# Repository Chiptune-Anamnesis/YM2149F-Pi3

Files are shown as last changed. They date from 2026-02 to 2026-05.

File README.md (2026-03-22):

# YM2149Fx3 MIDI Synthesizer

Triple YM2149F sound chip MIDI synthesizer with SID emulation, sample playback, and real-time sound design — powered by RP2040 (Raspberry Pi Pico).

## Features

### 9-Voice Polyphonic YM2149F Synthesis
- 3x YM2149F sound chips providing 9 independent tone voices
- **Four voice allocation modes:**
  - **MONO** — 1 voice per MIDI channel (ch1→voice 0A, ch2→0B, ... ch9→2C). Each channel has independent settings. True 9-channel multitimbral.
  - **SEMI** — 3 voices per chip, MIDI channel determines chip (ch1-3→Chip 0, ch4-6→Chip 1, ch7-9→Chip 2). Channel-based settings.
  - **POLY** — Up to 9-voice polyphony, any voice on any chip. Notes allocated to first free voice. Per-voice settings for individual voice tweaking and chip linking.
  - **MULTI** — Full polyphony like POLY, but settings follow MIDI channel instead of physical voice. Best for multi-channel DAW sequencing where each channel needs its own vibrato, envelope, detune, etc.
- Per-voice settings: detune (cents), octave shift, max volume, noise frequency
- Chip linking: mirror Chip 0 settings across chips for massive unison sounds
- MIDI channels 1-9 mapped to voices (3 per chip)

### SID Emulation Mode (NextSID)
- Software-emulated SID-style waveforms on Chips 1 and 2 (6 voices)
- Waveforms: Square and Pulse with adjustable duty cycle (default duty: 11)
- PWM sweep with configurable rate and depth
- Per-voice sync and ring modulation between voices within a chip
- Noise mixing per voice
- Portamento/glide fully supported in SID mode
- ~50kHz timer-driven volume flipping for waveform generation

### Sample Playback (SMPL Mode)
- Timer-based 8-bit PCM playback at 8000 Hz on Chip 2 (3 polyphonic voices)
- **Three sample sections:**
  - **DRUM** — 24 Bitkits drum samples: kicks, snares, hi-hats, toms, claps, cowbell, tambourine, shaker
  - **1SHT** — 24 Bitkits one-shot samples: beeps, blips, buzzes, glitches, metals, noises, stabs, vocals, zaps
  - **DIGI** — 16 legacy ST-Sound DigiDrum samples (classic Atari ST sounds)
- **Four playback modes:**
  - **SNGL** — Always play the selected sample
  - **SEQ** — Play samples sequentially (s00, s01, s02...)
  - **RND** — Random sample each trigger
  - **GM** — General MIDI drum map (notes 35-58 mapped to samples). OneShots use chromatic mapping from C2
- Per-section GM drum maps (Bitkits and DigiDrum have independent mappings)
- Pitch control: -12 to +12 semitones fine tuning plus -3 to +3 octave shift (8.8 fixed-point)
- Adjustable sample length (1-127, 127 = full sample)
- Volume scaling (1-15)
- Voice stealing with same-sample retrigger and round-robin allocation

### Effects (Chip 2)
- **Echo** — Delay, repeats, decay, volume
- **Arpeggio** — Speed, pattern, volume, octave range
- **Bit Crush** — Bit depth, sample rate, volume
- **Reverb** — Taps, spacing, decay, detune, volume
- **Chorus** — Detune spread with configurable volume
- Flexible routing: per-chip or global

### Per-Voice Modulation
- **Vibrato** — Rate (1.0-15.0 Hz), depth (0-200 cents), delay (0-2550ms)
- **Tremolo** — Rate (1.0-15.0 Hz), depth (0-100%)
- **Pitch Envelope** — Amount (0-24 semitones), time, direction (up/down)
- **ADSR Envelope** — Attack, decay, sustain, release
- **Portamento/Glide** — On/off per voice, adjustable speed

### Preset System
- Save and load complete synth states to flash (8 user slots)
- 4 factory SID presets
- Stores all voice settings, FX, SID config, sample section, mode, and more
- 8-character preset naming

### MIDI Implementation
- USB-MIDI and TRS-MIDI (Serial1 at 31250 baud) simultaneously
- MIDI channel filtering (per-channel, OMNI, or OFF)
- Channel remapping (route any incoming channel to any internal channel)
- 74 MIDI CC mappings covering voice, envelope, tremolo, FX, sample, and link controls — see [MIDI CC Map](MIDI_CC_MAP.md)
- Pitch bend (synth and sample modes)
- MIDI Real-Time: Start (0xFA), Continue (0xFB), Stop (0xFC) with proper note/controller reset
- MIDI clock sync
- Note range: A-1 to C8 (MIDI notes 9-108)
- Velocity curve with configurable gamma, min, and max

### Display & Controls
- 128x64 SH1106 OLED display (I2C on Wire1)
- Rotary encoder for menu navigation
- 3 analog pots with flexible parameter mapping (50+ assignable parameters)
- 5 visualization modes: Bars, Scope, Matrix (9-voice), Channel Matrix, Sample Waveform
- Hierarchical menu system: Main → Settings → Submenus (Pitch, Vibrato, Tremolo, Envelope, Glide, Pitch Env, SID, FX, Sample)

### Dual-Core Architecture (RP2040)
- **Core 0:** Audio engine — MIDI processing, YM2149 register writes, SID timer, sample timer, pitch modulation, effects
- **Core 1:** UI — OLED display, encoder input, pot reading, menu system
- Thread-safe communication via command queue and display snapshot
- Interrupt-safe bus arbitration for shared YM2149 data bus

## Hardware

### Sound Chips
- 3x YM2149F at 500 kHz clock
- 4-bit volume (0-15) per voice, 12-bit period registers (1-4095)

### Controller
- Raspberry Pi Pico (RP2040)
- Dual ARM Cortex-M0+ cores at 133 MHz
- 2MB flash for firmware + presets + sample data

### I/O
- 74HC138 3-to-8 decoder for chip selection
- CD74HC4067 multiplexer for 3 analog pots
- SH1106 128x64 OLED (I2C)
- Rotary encoder with push button
- TRS-MIDI input (Serial1)
- USB-MIDI
- 3x LEDs (active-low, one per chip)

### MIDI Routing
- **Channels 1-9** → Tone voices (3 chips x 3 voices)
  - Ch 1-3 → Chip 0, Ch 4-6 → Chip 1, Ch 7-9 → Chip 2
- **Channel 10** → Noise channel (Chip 2 voice C, when enabled)
- **Channels 11-16** → Wrapped to prevent out-of-bounds access

## Configuration

Compile-time settings in `config.h`:

| Parameter | Default | Description |
|---|---|---|
| `VELOCITY_GAMMA` | 0.3 | Velocity curve exponent (lower = more boost for soft notes) |
| `VELOCITY_MIN` | 4 | Minimum YM volume for softest velocity |
| `VELOCITY_MAX` | 15 | Maximum YM volume for loudest velocity |
| `EXPRESSION_AMOUNT` | 0.3 | CC7/CC11 volume influence (0.0 = bypass, 1.0 = full) |
| `ENABLE_NOISE_CHANNEL` | 0 | Enable MIDI channel 10 noise percussion |
| `USE_CC4_ENVELOPE` | 1 | Enable CC4 volume envelope shaping |

## Sample Conversion

The `tools/convert_samples.py` script converts WAV files to 8-bit unsigned PCM C arrays:

```bash
python tools/convert_samples.py
```

- Input: WAV files in `src/.../Samples/` (any sample rate, bit depth, stereo/mono)
- Output: `samples_drums.h` and `samples_oneshots.h` (8kHz, 8-bit, mono, normalized)
- Total sample data: ~92 KB (drums 31KB + oneshots 46KB + legacy DigiDrum 15KB)

## Build

PlatformIO project targeting `rpipico` with the `earlephilhower/arduino-pico` framework.

```bash
pio run -e pico
pio run -e pico -t upload
```

## Tips for Musicians

**Building patches from scratch:**
Load the INIT preset, set your poly mode, then shape one chip at a time.

**Layering for thickness:**
Set Link to ALL, then give each chip a different octave shift or detune. Three detuned copies of the same note across all 9 voices creates massive unison sounds.

**Expressive performance:**
Assign pots to the parameters you want to tweak live (filter-like sweeps with noise frequency, volume shaping with envelope controls). Use the mod wheel for vibrato and expression for dynamics.

**SID mode for richer timbres:**
Switch to SID mode when you need, metallic and aggressive bass textures.

**Effects as instruments:**
The arpeggiator and harmonizer can turn single notes into full patterns. Route effects to specific voices to keep some voices clean while others are processed.

**MIDI clock sync:**
When playing with a DAW, enable clock sync so echo repeats and arp steps lock to your tempo. The gate effect becomes a rhythmic sidechain when synced. (work in progress)

**Semi-poly for multi-timbral:**
Use semi-poly mode to give each chip its own sound. Send bass on channels 1-3, lead on 4-6, and pads on 7-9 for a complete arrangement from one device.

**Save often:**
You have 36 user preset slots. Save variations as you go - it's easy to lose a good sound by tweaking one parameter too far.

Buy it here: https://hobbychop.com

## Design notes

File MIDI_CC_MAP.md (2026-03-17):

# YM2149Fx3 MIDI CC Map

Complete MIDI Control Change mapping for the YM2149Fx3 synthesizer.
All CCs respond on the configured MIDI synth channel (or all channels in OMNI mode).

## Performance Controls

| CC | Name | Value | Description |
|----|---|---|---|
| 1 | Mod Wheel | 0-127 | Vibrato intensity |
| 4 | Foot Pedal | 0-127 | Volume envelope shape |
| 5 | Portamento Time | 0-127 | Glide speed (exponential curve) |
| 7 | Volume | 0-127 | Channel volume / expression |
| 11 | Expression | 0-127 | Channel volume (same as CC 7) |
| 64 | Sustain | 0-63=off, 64-127=on | Hold notes until release |
| 65 | Portamento | 0-63=off, 64-127=on | Enable pitch glide between notes |

## Pitch Bend

| Message | Range | Description |
|---|---|---|
| Pitch Bend | 14-bit (center=8192) | +/- 2 semitones. Works in both synth and sample modes |

## Vibrato

| CC | Name | Value | Description |
|----|---|---|---|
| 1 | Mod Wheel | 0-127 | Vibrato intensity (real-time) |
| 76 | Vibrato Rate | 0-127 | LFO speed (0-10 Hz) |
| 77 | Vibrato Depth | 0-127 | LFO range (0-2 semitones) |
| 85 | Vibrato Delay | 0-127 | Delay before vibrato starts (0-2000ms) |

## Voice Settings (CC 14-17)

Applied to all 9 voices simultaneously.

| CC | Name | Value | Description |
|----|---|---|---|
| 14 | Detune | 0-127 | Fine pitch (-50 to +50 cents, 64=center) |
| 15 | Octave | 0-127 | Octave shift (-3 to +3, 64=center) |
| 16 | Max Volume | 0-127 | Voice volume cap (maps to 0-15) |
| 17 | Noise Freq | 0-127 | Noise generator frequency (maps to 0-31) |

## Envelope ADSR (CC 18-21)

Applied to all 9 voices simultaneously.

| CC | Name | Value | Description |
|----|---|---|---|
| 18 | Attack | 0-127 | Attack time (0=instant, 127=slow) |
| 19 | Decay | 0-127 | Decay time |
| 20 | Sustain | 0-127 | Sustain level |
| 21 | Release | 0-127 | Release time (0=instant, 127=long) |

## Tremolo (CC 22-24)

Applied to all 9 voices simultaneously.

| CC | Name | Value | Description |
|----|---|---|---|
| 22 | Tremolo On | 0=off, 1-127 | Tremolo intensity |
| 23 | Tremolo Rate | 0-127 | LFO speed (1.0-15.0 Hz) |
| 24 | Tremolo Depth | 0-127 | Volume swing (0-100%) |

## Pitch Envelope (CC 25-27)

Applied to all 9 voices simultaneously.

| CC | Name | Value | Description |
|----|---|---|---|
| 9 | Pitch Env Amt (RT) | 0-127 | Real-time pitch sweep (0-2 semitones) |
| 10 | Pitch Env Shape (RT) | 0-127 | Real-time envelope shape |
| 25 | Pitch Env Amount | 0-127 | Per-voice sweep amount (0-24 semitones) |
| 26 | Pitch Env Time | 0-127 | Per-voice sweep speed |
| 27 | Pitch Env Dir | 0-63=down, 64-127=up | Sweep direction |

## FX Master (CC 28-30)

| CC | Name | Value | Description |
|----|---|---|---|
| 28 | FX Enable | 0-63=off, 64-127=on | Toggle effects on/off |
| 29 | FX Type | 0-127 | Select effect (see table below) |
| 30 | FX Routing | 0-127 | Route FX to specific voices/chips (maps to 0-8) |

### FX Type Values (CC 29)

| Value Range | Type | Description |
|---|---|---|
| 0-17 | NONE | Effects off |
| 18-35 | ECHO | Delay/echo effect |
| 36-53 | ARP | Arpeggiator |
| 54-71 | CRUSH | Bit crusher |
| 72-89 | REVERB | Pseudo reverb |
| 90-107 | CHORUS | Chorus/detune |
| 108-117 | HARM | Harmonizer |
| 118-127 | GATE | Rhythmic gate |

## Echo (CC 33-36)

| CC | Name | Value | Description |
|----|---|---|---|
| 33 | Echo Delay | 0-127 | Delay time (50-2000ms) |
| 34 | Echo Repeats | 0-127 | Number of echoes (1-10) |
| 35 | Echo Decay | 0-127 | Volume reduction per repeat (1-15) |
| 36 | Echo Volume | 0-127 | Echo output level (1-15) |

## Arpeggiator (CC 37-40)

| CC | Name | Value | Description |
|----|---|---|---|
| 37 | Arp Speed | 0-127 | Step timing (50-500ms) |
| 38 | Arp Pattern | 0-127 | Pattern: 0-31=UP, 32-63=DOWN, 64-95=UP/DOWN, 96-127=RANDOM |
| 39 | Arp Volume | 0-127 | Arp output level (1-15) |
| 40 | Arp Octave | 0-127 | Octave range (-2 to +2, 64=center) |

## Bit Crush (CC 41-43)

| CC | Name | Value | Description |
|----|---|---|---|
| 41 | Crush Bits | 0-127 | Bit depth (1-4, lower=crunchier) |
| 42 | Crush Rate | 0-127 | Sample-and-hold divisor (1-10) |
| 43 | Crush Volume | 0-127 | Crush output level (1-15) |

## Reverb (CC 44-48)

| CC | Name | Value | Description |
|----|---|---|---|
| 44 | Reverb Taps | 0-127 | Number of echo taps (2-6) |
| 45 | Reverb Spacing | 0-127 | Tap spacing (20-100ms) |
| 46 | Reverb Decay | 0-127 | Volume decay per tap (1-8) |
| 47 | Reverb Detune | 0-127 | Pitch variation per tap (-5 to +5 cents, 64=center) |
| 48 | Reverb Volume | 0-127 | Reverb output level (1-15) |

## Chorus (CC 49-52)

| CC | Name | Value | Description |
|----|---|---|---|
| 49 | Chorus Detune 1 | 0-127 | Voice 1 detune (-50 to +50 cents, 64=center) |
| 50 | Chorus Detune 2 | 0-127 | Voice 2 detune (-50 to +50 cents, 64=center) |
| 51 | Chorus Volume | 0-127 | Chorus output level (1-15) |
| 52 | Chorus Rate | 0-127 | LFO rate (0=static, up to 8.0 Hz) |

## Harmonizer (CC 53-55)

| CC | Name | Value | Description |
|----|---|---|---|
| 53 | Harm Chord | 0-127 | Chord type (maps to 0-11, see device menu for chord names) |
| 54 | Harm Volume | 0-127 | Harmony output level (1-15) |
| 55 | Harm Octave | 0-127 | Octave offset (-2 to +2, 64=center) |

## Gate (CC 56-60)

| CC | Name | Value | Description |
|----|---|---|---|
| 56 | Gate Rate | 0-127 | Gate cycle period (30-500ms) |
| 57 | Gate Pattern | 0-127 | Shape: 0-31=SQUARE, 32-63=RAMP, 64-95=TRI, 96-127=RANDOM |
| 58 | Gate Volume | 0-127 | Gate max level (1-15) |
| 59 | Gate Duty | 0-127 | On-time fraction (1/8 to 7/8) |
| 60 | Gate Seed | 0-127 | Random pattern seed (0-15) |

## Mode Switches (CC 68-78)

| CC | Name | Value | Description |
|----|---|---|---|
| 68 | Laser Mode | 0-63=off, 64-127=on | Toggle laser glitch effect |
| 69 | Laser Amount | 0-127 | Laser intensity |
| 70 | Poly Mode | 0-42=semi, 43-84=poly, 85-127=mono | Voice allocation mode |
| 71 | SID Mode | 0-63=YM, 64-127=SID | Toggle SID emulation (full mode reset) |
| 72 | Unison | 0-63=off, 64-127=on | Toggle unison mode |
| 73 | Unison Detune | 0-127 | Unison spread (0-50 cents) |
| 74 | SID Duty / Env Freq | 0-127 | PWM mode: duty cycle. Env mode: envelope frequency |
| 75 | SID Wave / Env Shape | 0-127 | PWM mode: square/pulse. Env mode: envelope shape |
| 78 | SID Detune | 0-127 | Per-voice PWM detune (64=center) |

## Sample Controls (CC 102-111)

These CCs are only active when SMPL mode is enabled.

### Global Sample Settings (CC 102-105)

| CC | Name | Value | Description |
|----|---|---|---|
| 102 | Sample Volume | 0-127 | Playback volume (1-15) |
| 103 | Sample Mode | 0-127 | 0-31=SNGL, 32-63=SEQ, 64-95=RND, 96-127=GM |
| 104 | Sample Section | 0-127 | 0-63=DRUMS, 64-95=1SHOTS, 96-127=DIGI |
| 105 | Sample Select | 0-127 | Select sample within section (scaled to section size) |

### Per-Sample Settings (CC 108-111)

These affect the currently selected sample (last played or selected via CC 105).

| CC | Name | Value | Description |
|----|---|---|---|
| 108 | Sample Pitch | 0-127 | Pitch offset (-12 to +12 semitones, 64=center) |
| 109 | Sample Octave | 0-127 | Octave shift (-3 to +3, 64=center) |
| 110 | Sample Length | 1-127 | Playback length (1=short, 127=full sample) |
| 111 | Sample Crush | 0-127 | Bitcrush amount (0=clean, maps to 0-7) |

## Link / Voice Settings (CC 106-107)

| CC | Name | Value | Description |
|----|---|---|---|
| 106 | Link Mode | 0-127 | 0-31=OFF, 32-63=CH1, 64-95=CH2, 96-127=ALL |
| 107 | Voice Link Mask | 0-127 | Bitmask of linked voices (maps to 0-7) |

## System Messages

| CC | Name | Description |
|----|---|---|
| 120 | All Sound Off | Silence all voices + clear FX state |
| 121 | Reset Controllers | Reset all CC values to defaults + clear FX |
| 123 | All Notes Off | Release all notes (respects sustain pedal) |

## Quick Reference by CC Number

| CC | Function | CC | Function | CC | Function |
|----|---|----|---|----|---|
| 1 | Mod Wheel | 33 | Echo Delay | 64 | Sustain |
| 4 | Foot Pedal | 34 | Echo Repeats | 65 | Portamento |
| 5 | Porta Time | 35 | Echo Decay | 68 | Laser On |
| 7 | Volume | 36 | Echo Volume | 69 | Laser Amt |
| 9 | PitchEnv Amt | 37 | Arp Speed | 70 | Poly Mode |
| 10 | PitchEnv Shape | 38 | Arp Pattern | 71 | SID Mode |
| 11 | Expression | 39 | Arp Volume | 72 | Unison |
| 14 | Detune | 40 | Arp Octave | 73 | Uni Detune |
| 15 | Octave | 41 | Crush Bits | 74 | SID Duty |
| 16 | Max Volume | 42 | Crush Rate | 75 | SID Wave |
| 17 | Noise Freq | 43 | Crush Volume | 76 | Vib Rate |
| 18 | Env Attack | 44 | Reverb Taps | 77 | Vib Depth |
| 19 | Env Decay | 45 | Reverb Space | 78 | SID Detune |
| 20 | Env Sustain | 46 | Reverb Decay | 85 | Vib Delay |
| 21 | Env Release | 47 | Reverb Det | 102 | Smpl Vol |
| 22 | Tremolo On | 48 | Reverb Vol | 103 | Smpl Mode |
| 23 | Tremolo Rate | 49 | Chorus Det1 | 104 | Smpl Sect |
| 24 | Tremolo Depth | 50 | Chorus Det2 | 105 | Smpl Select |
| 25 | PEnv Amount | 51 | Chorus Vol | 106 | Link Mode |
| 26 | PEnv Time | 52 | Chorus Rate | 107 | Link Mask |
| 27 | PEnv Dir | 53 | Harm Chord | 108 | Smpl Pitch |
| 28 | FX Enable | 54 | Harm Volume | 109 | Smpl Octave |
| 29 | FX Type | 55 | Harm Octave | 110 | Smpl Length |
| 30 | FX Routing | 56 | Gate Rate | 111 | Smpl Crush |
| | | 57 | Gate Pattern | 120 | All Snd Off |
| | | 58 | Gate Volume | 121 | Reset Ctrl |
| | | 59 | Gate Duty | 123 | All Notes Off |
| | | 60 | Gate Seed | | |

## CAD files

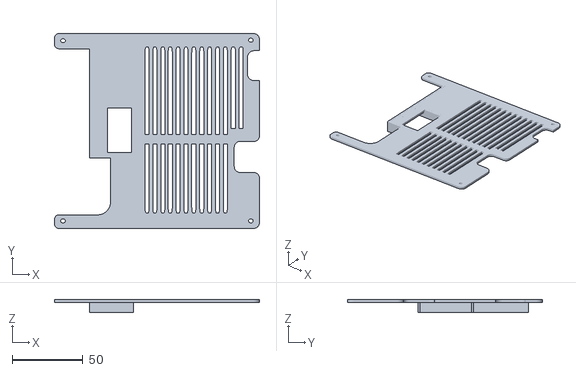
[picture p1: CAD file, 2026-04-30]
ym2149f-pi-top2.stl
144.8 x 137.7 x 9.36

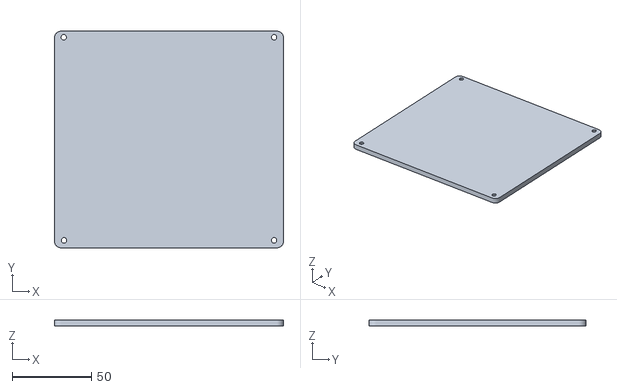
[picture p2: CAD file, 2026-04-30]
ym2149f-pi-btm.stl
144.5 x 136.8 x 4.08

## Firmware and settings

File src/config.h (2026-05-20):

#pragma once
#include <Arduino.h>

// ============================================================================
// PIN DEFINITIONS
// ============================================================================

// OLED Display (128x64 SH1106 I2C on Wire1)
#define PIN_OLED_SDA 14
#define PIN_OLED_SCL 15
#define SCREEN_WIDTH 128
#define SCREEN_HEIGHT 64

// Rotary Encoder (for menu navigation)
#define PIN_ENCODER_A 27
#define PIN_ENCODER_B 28
#define PIN_ENCODER_BTN 22  // Encoder button on GPIO 22 (shares with LED2, with internal pullup)

// CD74HC4067 Multiplexer for pots only
#define PIN_MUX_S0 17   // CD74HC4067 S0 select
#define PIN_MUX_S1 18   // CD74HC4067 S1 select
#define PIN_MUX_S2 19   // CD74HC4067 S2 select
#define PIN_MUX_SIG 26  // ADC0 - CD74HC4067 SIG

// ============================================================================
// FEATURE TOGGLES
// ============================================================================

// Toggle YM file streaming via USB CDC
#define USE_YMPLAYER_SERIAL 0

// Toggle noise channel support (MIDI channel 10)
#define ENABLE_NOISE_CHANNEL 0

// CC4 volume envelope
#define USE_CC4_ENVELOPE 1

// ============================================================================
// VELOCITY & EXPRESSION
// ============================================================================

#define VELOCITY_GAMMA_DEFAULT  0.15f // Default gamma curve (index 10 = most aggressive)
#define VELOCITY_MIN_DEFAULT    2     // Default minimum YM volume (0-15)
#define VELOCITY_MAX    15            // Maximum YM volume (1-15)
#define EXPRESSION_AMOUNT 0.3f        // How much CC7/CC11 affects volume (0.0-1.0)

// Runtime-adjustable velocity settings (set from MIDI menu, persisted to flash)
extern float velocityGamma;
extern uint8_t velocityMin;

// Velocity curve index (0-10) to gamma lookup
// 0 = most dynamic (soft notes quiet), 10 = most aggressive (everything loud)
static const float velocityCurveTable[11] = {
  3.0f, 2.5f, 2.0f, 1.7f, 1.5f, 1.2f, 1.0f, 0.7f, 0.5f, 0.3f, 0.15f
};

// ============================================================================
// PITCH & MODULATION
// ============================================================================

#define OCTAVE_SHIFT 0          // Global octave transpose in semitones
#define DEFAULT_VIB_RATE  7.0f  // Hz
#define DEFAULT_VIB_RANGE 0.5f  // semitone

// Portamento
#define PORTA_MIN 0.005f
#define PORTA_MAX 0.5f

// Note range
#define MIDI_NOTE_MIN 9    // A-1 = 13.75 Hz (extended bass range)
#define MIDI_NOTE_MAX 108  // C8

// ============================================================================
// SID MODE DEFAULTS
// ============================================================================

#define SID_MAX_PATTERN 32
#define SID_TIMER_INTERVAL_US 20  // Timer fires every 20µs (~50kHz) for NextSID volume flipping

// ============================================================================
// TIMING
// ============================================================================

#define LED_FLASH_MS 100
#define ENCODER_DEBOUNCE_MS 30
#define DISPLAY_UPDATE_MS 20
#define PITCH_MOD_UPDATE_MS 3

// ============================================================================
// MIDI TO CHIP MAPPING
// ============================================================================

// Maps MIDI channels 0-15 to YM chips 0-2
// Channels 1-3 (idx 0-2) → Chip 0, Channels 4-6 (idx 3-5) → Chip 1, Channels 7-9 (idx 6-8) → Chip 2
// Channels 10-16 (idx 9-15) wrap to Chip 0/1/2 to prevent out-of-bounds
const uint8_t midiToChip[16] = {0,0,0, 1,1,1, 2,2,2, 0,0,0, 1,1,1, 2};

// Note: YM_CLOCK_HZ, LED_ON, LED_OFF are defined in YM2149.h
// PIN_MIDI_TX and PIN_MIDI_RX are defined in YM2149.h

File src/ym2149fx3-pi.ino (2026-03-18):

// ============================================================================
// YM2149Fx3 - Triple YM2149 MIDI Synthesizer
// Main sketch file
// ============================================================================

#include <Arduino.h>
#include <Wire.h>
#include "hardware/timer.h"

// Project modules
#include "config.h"
#include "YM2149.h"
#include "encoder.h"
#include "sid_mode.h"
#include "effects.h"
#include "voice_manager.h"
#include "display.h"
#include "midi_handler.h"
#include "settings.h"
#include "dual_core.h"
#include "fx_chip.h"
#include "sample_player.h"
#include "preset.h"
#include "splash.h"

#if USE_YMPLAYER_SERIAL
  #include "YMPlayerSerial.h"
  YMPlayerSerial player;
#endif

// ============================================================================
// GLOBAL INSTANCES
// ============================================================================

YM2149 ym;

// ============================================================================
// SETUP
// ============================================================================

void setup() {
  // Initialize USB FIRST - must happen early for enumeration
  midiInit();

  delay(500);  // Wait for power rails and external ICs to stabilize

  // Initialize YM2149 hardware
  ym.begin();

  // Initialize OLED display
  if (displayInit()) {
    delay(50);

    drawSplashCube(display);
  }

  // Initialize multiplexer pins
  pinMode(PIN_MUX_S0, OUTPUT);
  pinMode(PIN_MUX_S1, OUTPUT);
  pinMode(PIN_MUX_S2, OUTPUT);
  pinMode(PIN_MUX_SIG, INPUT);

  // Initialize encoder
  encoderInit();

  delay(100);

  // Reset all YM2149 chips to known state
  for (uint8_t c = 0; c < 3; c++) {
    ym.write(c, 0x08, 0x00);  // Channel A volume = 0
    ym.write(c, 0x09, 0x00);  // Channel B volume = 0
    ym.write(c, 0x0A, 0x00);  // Channel C volume = 0
    ym.write(c, 0x07, 0b00111111);  // All disabled
    ym.write(c, 0x00, 0x00);
    ym.write(c, 0x01, 0x00);
    ym.write(c, 0x02, 0x00);
    ym.write(c, 0x03, 0x00);
    ym.write(c, 0x04, 0x00);
    ym.write(c, 0x05, 0x00);
  }

  delay(50);

  // LED startup animation (only LED0 and LED1)
  for (uint8_t i = 0; i < 2; i++) {
    ym.setLED(i, false);  // Turn ON
    delay(100);
    ym.setLED(i, true);   // Turn OFF
    delay(50);
  }

  // Initialize note-to-period lookup table
  initNotePeriodLUT();

  // Initialize all YM chips: enable tones, silence all voices
  for (uint8_t c = 0; c < 3; c++) {
    enableTones(c);
    for (uint8_t v = 0; v < 3; v++) stopVoice(c, v);
  }

  // Initialize settings FIRST (other modules depend on chipSettings)
  settingsInit();

  // Initialize preset system (reads header from flash)
  presetInit();

  // Initialize SID mode
  sidInit();

  // If device booted with SID mode enabled, activate it now
  if (sidModeGlobal) {
    sidModeInit();
  }

  // Initialize effects
  effectsInit();

  // Initialize voice manager
  voiceManagerInit();

  // Initialize FX chip module
  fxInit();

  // Initialize sample player (4000 Hz timer for digidrum playback)
  samplePlayerInit();

  // TRS MIDI on UART1 (GPIO 20/21)
  Serial2.setTX(PIN_MIDI_TX);
  Serial2.setRX(PIN_MIDI_RX);
  Serial2.begin(31250);

#if USE_YMPLAYER_SERIAL
  Serial.begin(115200);
  player.begin();
#endif

  // Initialize dual-core communication
  dualCoreInit();

  // Launch Core 1 for display/encoder handling
  core1Running = true;
  multicore_launch_core1(core1Entry);
}

// ============================================================================
// MAIN LOOP
// ============================================================================

void loop() {
  // If Core 1 needs to write flash, enter RAM-safe spin loop
  if (flashWriteInProgress) {
    core0FlashSafeLoop();
    return;
  }

  // TRS MIDI (UART1 = Serial2)
  while (Serial2.available()) {
    parseSerialMidi(Serial2.read());
  }

  // LED flash timing (only LED0 and LED1)
  unsigned long now = millis();
  for (uint8_t c = 0; c < 2; c++) {
    if (ledOnTime[c] && now - ledOnTime[c] >= LED_FLASH_MS) {
      ym.setLED(c, true);  // Turn OFF
      ledOnTime[c] = 0;
    }
  }

  // USB MIDI
#if !USE_YMPLAYER_SERIAL
  processUsbMidi();
#else
  player.update();
#endif

  // Pitch modulation and envelope update (~3ms)
  static unsigned long lastPitchUpdate = millis();
  unsigned long m = millis();
  if (m - lastPitchUpdate >= PITCH_MOD_UPDATE_MS) {
    lastPitchUpdate = m;

    // Update all voice envelopes independently (per-voice)
    updateAllEnvelopes();

    // Update pitch modulation per channel
    for (uint8_t ch = 0; ch < 9; ++ch) {
      updatePitchMod(ch);
    }
  }

  // Update pot readings and apply mapped parameters
  updatePots();

  // Process commands from Core 1 (display/encoder)
  processCommands();

  // Update FX chip effects (echo, arp, etc.)
  fxUpdate();
}

// ============================================================================
// NOISE CHANNEL (optional)
// ============================================================================

#if ENABLE_NOISE_CHANNEL
void noiseOn(uint8_t note, uint8_t vel) {
  uint8_t chip = 2;
  uint8_t nf = constrain((int)note - 24, 2, 31);
  ymSafeWrite(chip, 6, nf);
  ymSafeWrite(chip, 7, 0b00011100);
  ymSafeWrite(chip, 8 + 2, vel >> 3);
}

void noiseOff() {
  uint8_t chip = 2;
  ymSafeWrite(chip, 8 + 2, 0);
  ymSafeWrite(chip, 7, 0b00111000);
}
#endif

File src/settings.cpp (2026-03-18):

#include "settings.h"
#include "effects.h"
#include "voice_manager.h"
#include "encoder.h"
#include "YM2149.h"
#include "sid_mode.h"
#include "fx_chip.h"
#include "sample_player.h"
#include "preset.h"  // For saveGlobalSettings()
#include <hardware/sync.h>  // For save_and_disable_interrupts()

extern YM2149 ym;

// ============================================================================
// SETTINGS STATE
// ============================================================================

VoiceSettings voiceSettings[9];
SettingsTarget currentTarget = TARGET_ALL;

// Default pot assignments: Decay, Sustain, Release (basic envelope control)
PotAssignment potAssignments[3] = {
  { PCAT_ENVELOPE, 1, TARGET_ALL, 0 },  // POT1: Envelope Decay → ALL
  { PCAT_ENVELOPE, 2, TARGET_ALL, 0 },  // POT2: Envelope Sustain → ALL
  { PCAT_ENVELOPE, 3, TARGET_ALL, 0 }   // POT3: Envelope Release → ALL
};

// Chip link: when enabled, all 3 voices on a chip play the same note
bool chipLink[3] = {false, false, false};

// Global link mode: 0=OFF, 1=CH1, 2=CH2, 3=ALL
uint8_t linkMode = LINK_OFF;

// Voice link mask: which Chip 0 voices participate in linking (default OFF)
uint8_t voiceLinkMask = 0;  // OFF by default - voices play independently

int potValues[3] = {0};
int potLastValues[3] = {0};

// MIDI channel settings (volatile for cross-core access)
volatile uint8_t midiSynthChannel = MIDI_CHANNEL_OMNI;  // OMNI by default (respond to all channels)

// MIDI channel routing (volatile for cross-core access)
// Default: identity mapping (no remapping)
volatile uint8_t midiChannelRemap[16] = {
  MIDI_REMAP_NONE, MIDI_REMAP_NONE, MIDI_REMAP_NONE, MIDI_REMAP_NONE,
  MIDI_REMAP_NONE, MIDI_REMAP_NONE, MIDI_REMAP_NONE, MIDI_REMAP_NONE,
  MIDI_REMAP_NONE, MIDI_REMAP_NONE, MIDI_REMAP_NONE, MIDI_REMAP_NONE,
  MIDI_REMAP_NONE, MIDI_REMAP_NONE, MIDI_REMAP_NONE, MIDI_REMAP_NONE
};

// USB mode setting (takes effect on reboot)
uint8_t usbMode = USB_MODE_MIDI;  // USB-MIDI by default

// Device mode settings (YM / SID / SMPL — only one active at a time)
volatile bool sidModeGlobal = false;
volatile bool sampleModeGlobal = false;
uint8_t sidDutyChip[2] = {11, 11};         // Default duty for both chips

// Per-sample pitch + length arrays (indexed by sampleFlatIndex)
int8_t  samplePitchArr[TOTAL_SAMPLE_COUNT]  = {0};  // All default to 0
int8_t  sampleOctaveArr[TOTAL_SAMPLE_COUNT] = {0};  // All default to 0
uint8_t sampleLengthArr[TOTAL_SAMPLE_COUNT];         // Initialized to 127 in settingsInit()
uint8_t sampleCrushArr[TOTAL_SAMPLE_COUNT] = {0};   // All default to 0 (clean)

// Display brightness
uint8_t displayBrightness = DISPLAY_BRIGHTNESS_DEFAULT;

// Pot default assignments (persisted to flash)
PotAssignment potDefaultAssignments[3] = {
  { PCAT_ENVELOPE, 1, TARGET_ALL, 0 },  // POT1: Envelope Decay → ALL
  { PCAT_ENVELOPE, 2, TARGET_ALL, 0 },  // POT2: Envelope Sustain → ALL
  { PCAT_ENVELOPE, 3, TARGET_ALL, 0 }   // POT3: Envelope Release → ALL
};

// Smoothing for pot readings
static const int POT_THRESHOLD = 20;  // ADC units before registering change
static const int POT_ADC_MAX = 1000;  // Actual pot range (10k pot reads ~0-1000)

// ============================================================================
// INITIALIZATION
// ============================================================================
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

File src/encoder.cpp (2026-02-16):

#include "encoder.h"

// ============================================================================
// ENCODER STATE
// ============================================================================

static volatile int8_t encoderPosition = 0;
static volatile uint8_t encoderLastState = 0;

static bool lastButtonState = HIGH;
static unsigned long lastButtonStableTime = 0;
static bool rawButtonState = HIGH;

// Long press detection
#define LONG_PRESS_MS 1000
static unsigned long buttonPressStart = 0;
static bool longPressTriggered = false;
static bool suppressNextRelease = false;  // Suppress button release after long press

// ============================================================================
// ENCODER ISR
// ============================================================================

void encoderISR() {
  uint8_t a = digitalRead(PIN_ENCODER_A);
  uint8_t b = digitalRead(PIN_ENCODER_B);
  uint8_t currentState = (a << 1) | b;

  // Simple and reliable: check specific transitions
  // CW:  00->10->11->01->00  (A leads B)
  // CCW: 00->01->11->10->00  (B leads A)

  uint8_t transition = (encoderLastState << 2) | currentState;

  switch (transition) {
    // Clockwise transitions
    case 0b0010:  // 00 -> 10
    case 0b1011:  // 10 -> 11
    case 0b1101:  // 11 -> 01
    case 0b0100:  // 01 -> 00
      encoderPosition++;
      break;

    // Counter-clockwise transitions
    case 0b0001:  // 00 -> 01
    case 0b0111:  // 01 -> 11
    case 0b1110:  // 11 -> 10
    case 0b1000:  // 10 -> 00
      encoderPosition--;
      break;
  }

  encoderLastState = currentState;
}

// ============================================================================
// ENCODER FUNCTIONS
// ============================================================================

void encoderInit() {
  // Initialize encoder pins with internal pull-ups
  pinMode(PIN_ENCODER_A, INPUT_PULLUP);
  pinMode(PIN_ENCODER_B, INPUT_PULLUP);
  pinMode(PIN_ENCODER_BTN, INPUT_PULLUP);

  // Initialize encoder state
  uint8_t a = digitalRead(PIN_ENCODER_A);
  uint8_t b = digitalRead(PIN_ENCODER_B);
  encoderLastState = (a << 1) | b;

  // Attach interrupts for reliable encoder reading
  attachInterrupt(digitalPinToInterrupt(PIN_ENCODER_A), encoderISR, CHANGE);
  attachInterrupt(digitalPinToInterrupt(PIN_ENCODER_B), encoderISR, CHANGE);
}

int getEncoderDelta() {
  // Atomic read and reset
  noInterrupts();
  int8_t pos = encoderPosition;
  encoderPosition = 0;
  interrupts();

  // Convert accumulated position to menu movement
  // Threshold of 4 = one detent on most encoders
  // Note: direction reversed (negate result)
  if (pos >= 4) return -1;
  if (pos <= -4) return 1;

  // If less than threshold, put it back for accumulation
  if (pos != 0) {
    noInterrupts();
    encoderPosition += pos;
    interrupts();
  }

  return 0;
}

bool encoderButtonPressed() {
  bool currentRead = digitalRead(PIN_ENCODER_BTN);

  // If reading changed, reset stability timer
  if (currentRead != rawButtonState) {
    rawButtonState = currentRead;
    lastButtonStableTime = millis();
  }

  // Only update debounced state if signal has been stable for debounce period
  if ((millis() - lastButtonStableTime) > ENCODER_DEBOUNCE_MS) {
    if (rawButtonState != lastButtonState) {
      bool wasReleased = (lastButtonState == LOW && rawButtonState == HIGH);
      lastButtonState = rawButtonState;

      // If this release follows a long press, suppress it
      if (wasReleased && suppressNextRelease) {
        suppressNextRelease = false;
        return false;
      }
      return wasReleased;
    }
  }

  return false;
}

bool encoderButtonLongPressed() {
  bool currentRead = digitalRead(PIN_ENCODER_BTN);

  if (currentRead == LOW) {  // Button held down
    if (buttonPressStart == 0) {
      buttonPressStart = millis();
    } else if (!longPressTriggered && (millis() - buttonPressStart >= LONG_PRESS_MS)) {
      longPressTriggered = true;
      suppressNextRelease = true;  // Don't trigger short press on release
      return true;  // Long press detected
    }
  } else {  // Button released
    buttonPressStart = 0;
    longPressTriggered = false;
  }
  return false;
}

// ============================================================================
// MULTIPLEXER FUNCTIONS
// ============================================================================

bool readMuxChannel(uint8_t channel) {
  // Set channel select pins (S0-S2 for channels 0-7, S3 tied to GND)
  digitalWrite(PIN_MUX_S0, (channel & 0x01) ? HIGH : LOW);
  digitalWrite(PIN_MUX_S1, (channel & 0x02) ? HIGH : LOW);
  digitalWrite(PIN_MUX_S2, (channel & 0x04) ? HIGH : LOW);

  // Small delay for multiplexer switching
  delayMicroseconds(5);

  // Read from signal pin as digital
  return digitalRead(PIN_MUX_SIG);
}

int readMuxAnalog(uint8_t channel) {
  // Set channel select pins (S0-S2 for channels 0-7, S3 tied to GND)
  digitalWrite(PIN_MUX_S0, (channel & 0x01) ? HIGH : LOW);
  digitalWrite(PIN_MUX_S1, (channel & 0x02) ? HIGH : LOW);
  digitalWrite(PIN_MUX_S2, (channel & 0x04) ? HIGH : LOW);

  // Small delay for multiplexer switching
  delayMicroseconds(10);

  // Read from signal pin as analog (0-4095 on Pico ADC)
  return analogRead(PIN_MUX_SIG);
}

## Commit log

2026-03-18 chip 2 not init bug
    [display.cpp, display.h, display_input.cpp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]
2026-03-18 fix chip 2 init
    [preset.cpp, preset.h, ym2149fx3-pi.ino]
2026-03-22 Global velocity in settings
2026-05-20 1.7.2 - Fix SID effects in Mono Mode
    [config.h, display.h, display_input.cpp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]
